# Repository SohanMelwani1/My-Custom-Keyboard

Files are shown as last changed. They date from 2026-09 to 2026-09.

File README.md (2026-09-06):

# My-Custom-Keyboard
My own Custom 60% Mechanical Keyboard

[Click here to open and view firmware repository](https://github.com/SohanMelwani1/RMK-My-custom-Keyboard)

BOM link: https://docs.google.com/spreadsheets/d/1pmS31pF6GHp4k1bNOez-trRHEgPxX3IoW4xAfGn9qzQ/edit?gid=0#gid=0

# Features
- 3 Macros
- Anti-Ghosting
- customizable keycaps and switches
- swappable switches without needing to re-solder it
- 60% mechanical keyboard
- no screws required
- 3d printed case
- Matrix layout
- 61 keys

___

While making this I learnt How Matrix keyboards work, types of mounting of keyboards, Schematic and how to use it, PCB wiring, importing pcb to fusion and creating case, Firmware and about keyboards in general, this was my first PCB I have ever designed

___

PCB without ground



PCB



PCB 3d view



Schematic stabilizers and mounting hole



Schematic RaspberryPi_Pico



Schematic Matrix with switches and diodes



Full schematic



Full 3d model



3d model case, plate and top frame



3d model case 



3d model plate


3d model top frame


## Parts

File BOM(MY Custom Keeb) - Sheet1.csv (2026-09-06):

Material/part | Amount | INR Price(including Tax and shipping) | USD price(including tax and shipping) | Link | Note
Gateron Hotswap sockets | 62 Pieces | ₹750 | $7.94 | https://stackskb.com/store/gateron-hotswap-sockets/
PLA matte(numakers) | 1Kg | ₹868.5 | $9.20 | https://india.numakers.com/products/pla-matte?variant=45679205482665
Key cap set | Set of 1 | ₹1399 | $14.82 | https://meckeys.com/shop/accessories/keyboard-accessories/keycaps/comic-style-keycap-set/
Gateron Mechanical Switches | 7 sets(10 per set) | ₹1260 | $13.34 | https://www.thecosmicbyte.com/product/gateron-mechanical-switches-compatible-with-cosmic-byte-hot-swappable-keyboards-qty-1pc/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
RaspberryPi_PICO | 1 piece | ₹552 | $5.85 | https://sharvielectronics.com/product/raspberry-pi-pico-rp2040-with-basic-kit/ | Ordering with diode(so i combined both shiping to make it cheaper
1N4148W-T4 (Diode) | 80 pieces(minimum) | ₹189 | $2.00 | https://sharvielectronics.com/product/1n4148w-t4-high-speed-fast-switching-diode-sod-123-package/ | Ordering with RaspbberyPi_PICO(so i combined both shiping to make it cheaper
Soldering Iron | 1 Piece | ₹299 | $3.17 | https://www.amazon.in/THEMISTO-passion-Themisto-Beginners-Soldering/dp/B07PM6134P/ref=sr_1_6?sr=8-6
Heat resistant gloves(for soldering) | 1 pair of gloves | ₹270 | $2.86 | https://www.amazon.in/KOOCU-Resistant-Temperature-Breathable-Electronics/dp/B0H7YN7SBV
Stabalizer | 1 set | ₹730 | $7.73 | https://neomacro.in/products/cherry-stabilizer-set-geon-and-c3?_pos=3&_sid=9a6134911&_ss=r
PCB | 5(minimum) | ₹4635 | $49.09 | https://robu.in/product/online-pcb-manufacturing-service/
Total cost |  | ₹10,952.5 | $116.00

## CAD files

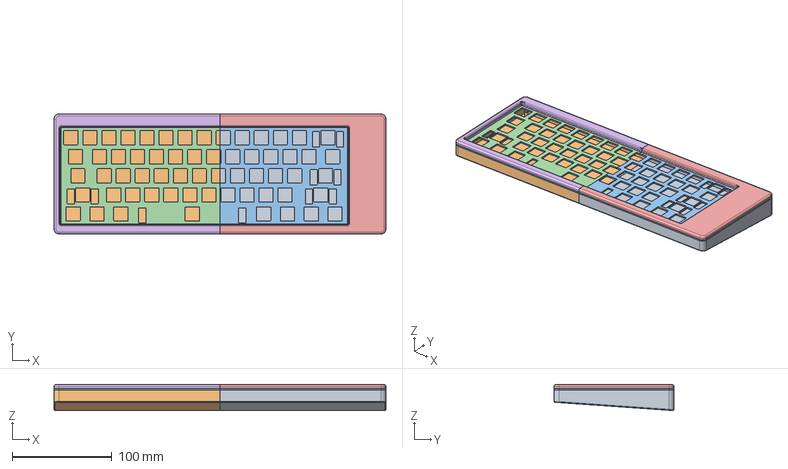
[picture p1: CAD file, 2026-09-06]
CAD(print)/Keeb-full Case(step).step
332.0 x 120.0 x 26.2 mm
My-keebs_PCB

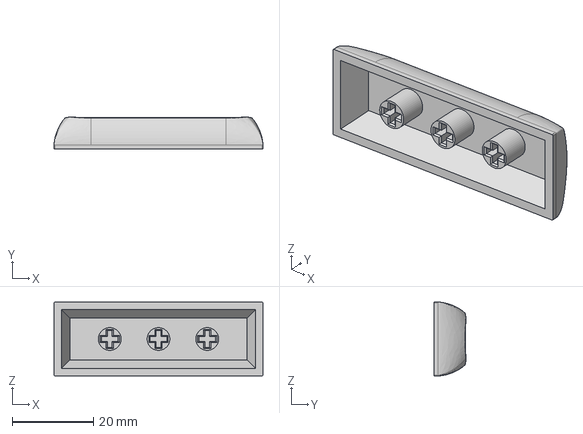
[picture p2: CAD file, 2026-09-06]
Assets/keycaps/DSA 2.75u.step
51.5 x 7.91 x 18.2 mm

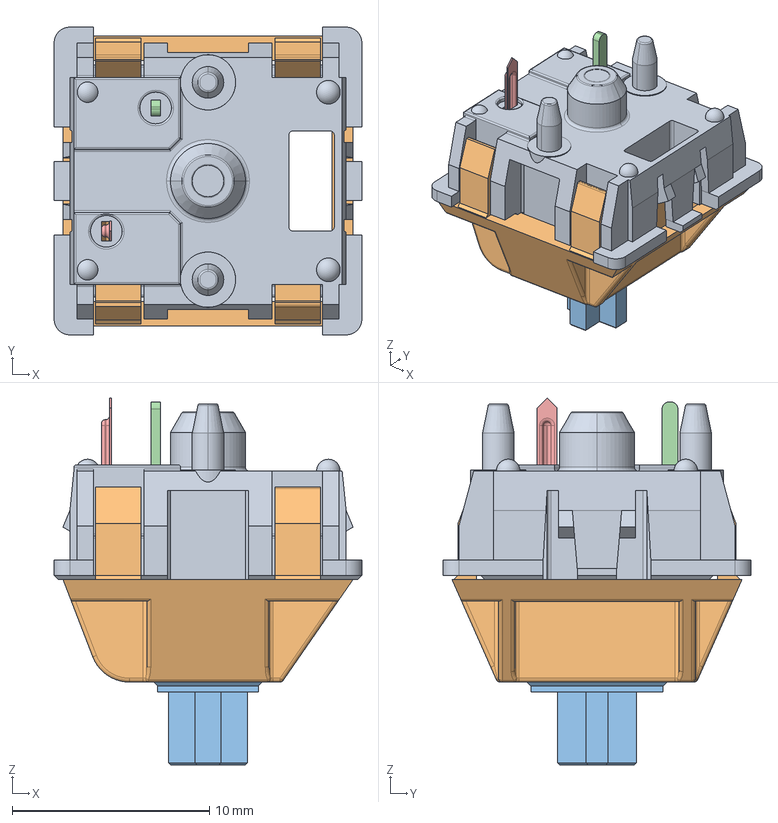
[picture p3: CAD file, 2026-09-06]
Assets/Switch/MX_switch.stp
15.6 x 15.6 x 18.6 mm
MX_DOWN
MX_UP
UP_MX
MX_PIN
MX_SPRING
MX_CLICK

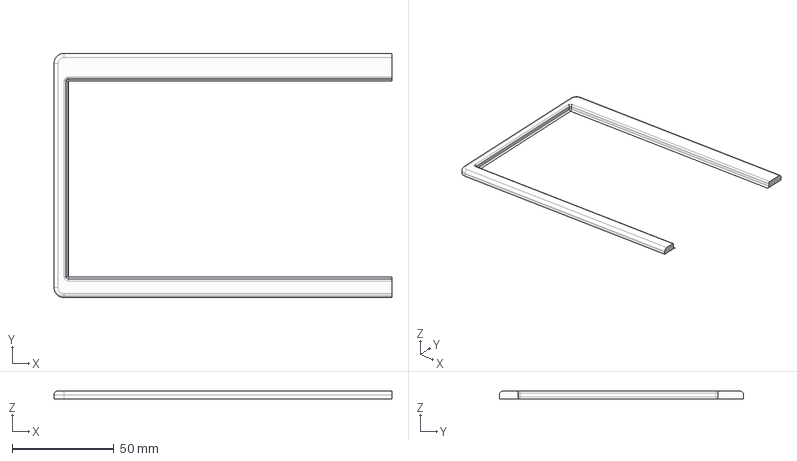
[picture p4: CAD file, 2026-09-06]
CAD(print)/Keeb top frame-left(step).step
166.0 x 120.0 x 4.00 mm
My-keebs_PCB

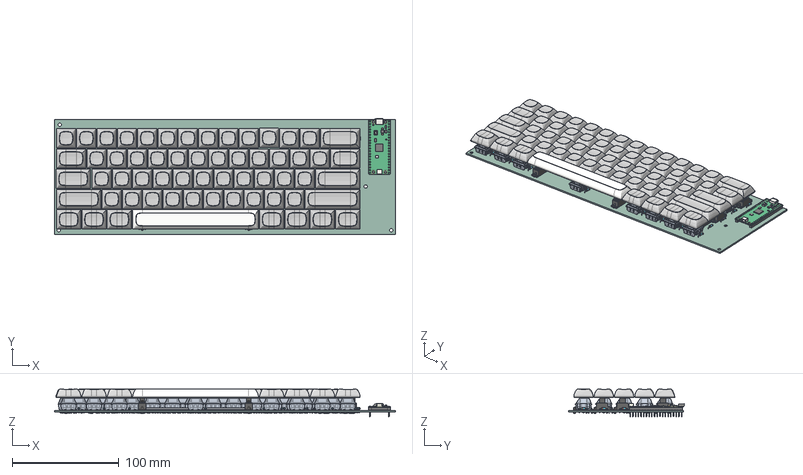
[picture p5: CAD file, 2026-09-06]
PCB/Keeb.step
320.0 x 108.8 x 26.3 mm
D_DO-35_SOD27_P7.62mm_Horizontal x 61
MX_DOWN x 61
MX_UP x 61
UP_MX x 61
MX_PIN x 61
MX_SPRING x 61
MX_CLICK x 61
MX Mount v1 x 46
RaspberryPi_Pico_H_Module_KiCad
RaspberryPi_Pico_Header_DIP-40_H2.54mm_KiCad
DSA 1.5u x 2
DSA 1.25u x 7
body_l x 5
stem_l x 5
body_r x 5
stem_r x 5
wire_2u x 4
DSA 2.25u x 2
DSA Spacebar 6.25u (50mm spacing)
DSA 2.75u
DSA 1.75u
wire_6_25u
DSA 2u
My-keebs_PCB

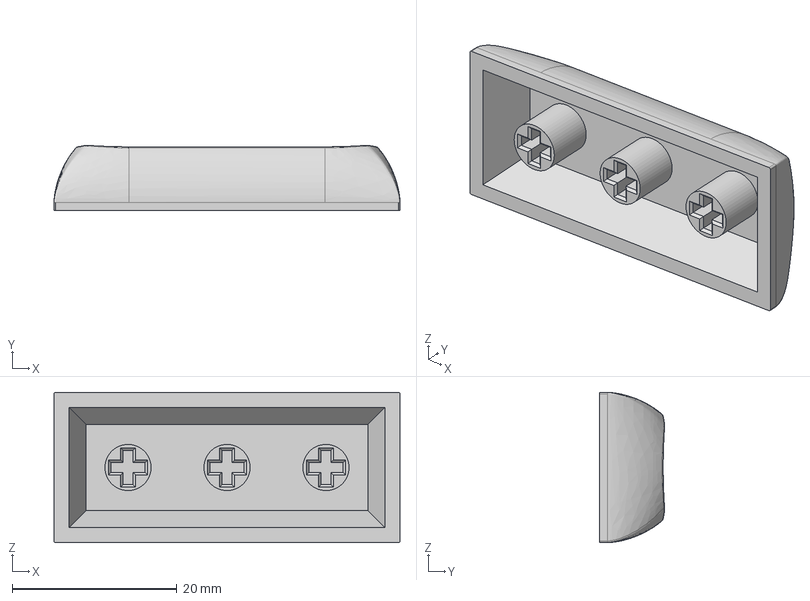
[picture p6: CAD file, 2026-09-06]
Assets/keycaps/DSA 2.25u.step
42.0 x 7.91 x 18.2 mm

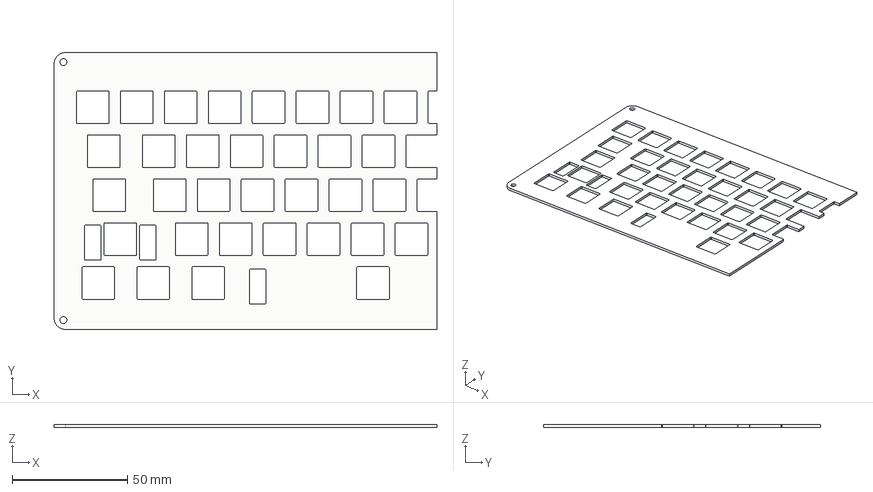
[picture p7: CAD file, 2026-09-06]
CAD(print)/Keeb plate-left(step).step
166.0 x 120.0 x 1.50 mm
My-keebs_PCB

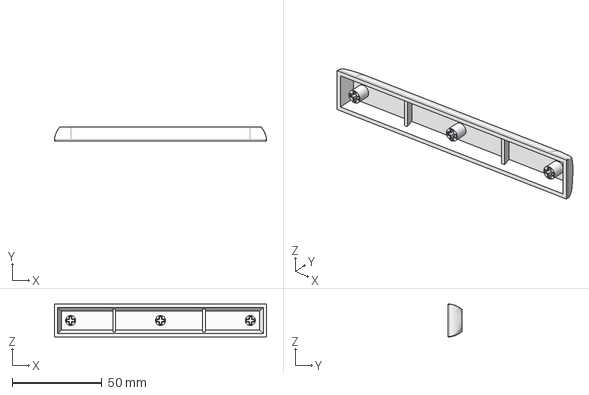
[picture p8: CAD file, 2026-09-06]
Assets/keycaps/DSA Spacebar 6.25u (50mm spacing).step
118.0 x 8.00 x 18.2 mm

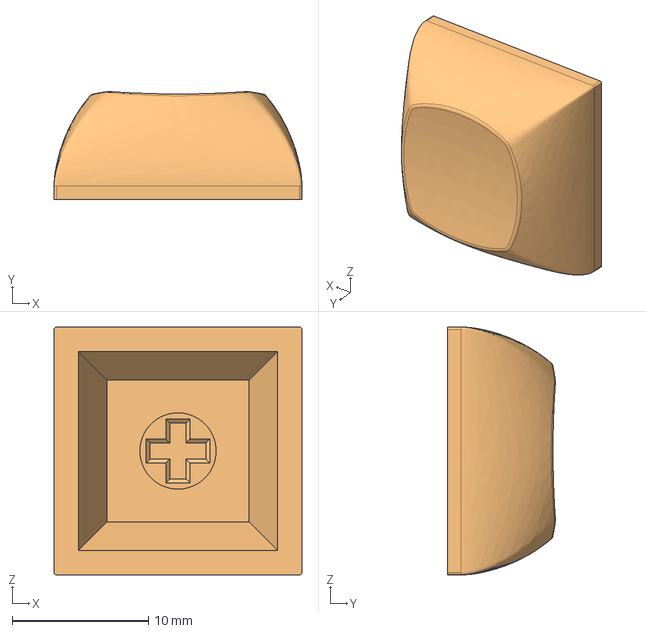
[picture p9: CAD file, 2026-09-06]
Assets/keycaps/DSA 1u.step
18.2 x 7.91 x 18.2 mm

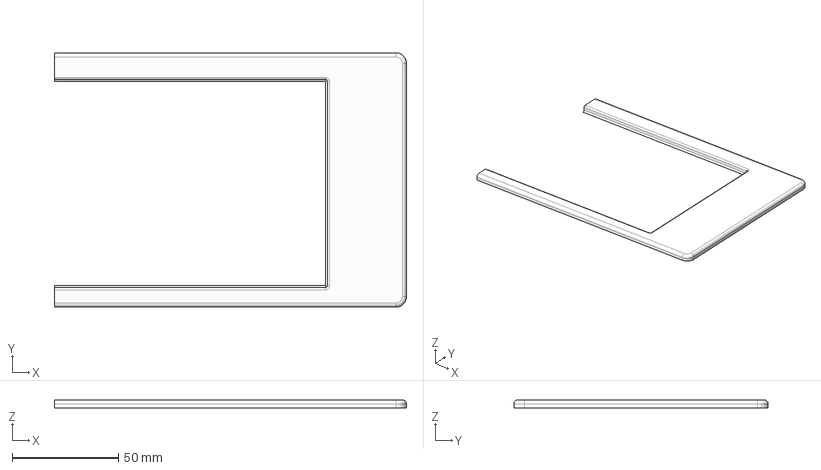
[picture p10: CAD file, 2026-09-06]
CAD(print)/Keeb top fram-right(step).step
166.0 x 120.0 x 4.00 mm
My-keebs_PCB

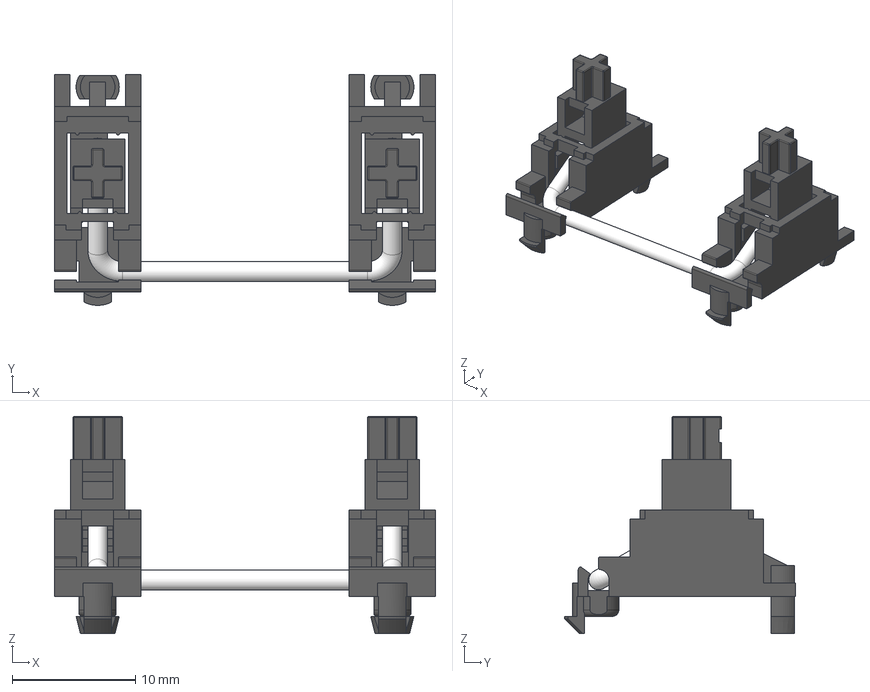
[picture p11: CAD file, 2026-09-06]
Assets/keycaps/stabilizer_2u.step
30.9 x 18.7 x 17.6 mm
body_l
stem_l
body_r
stem_r
wire_2u

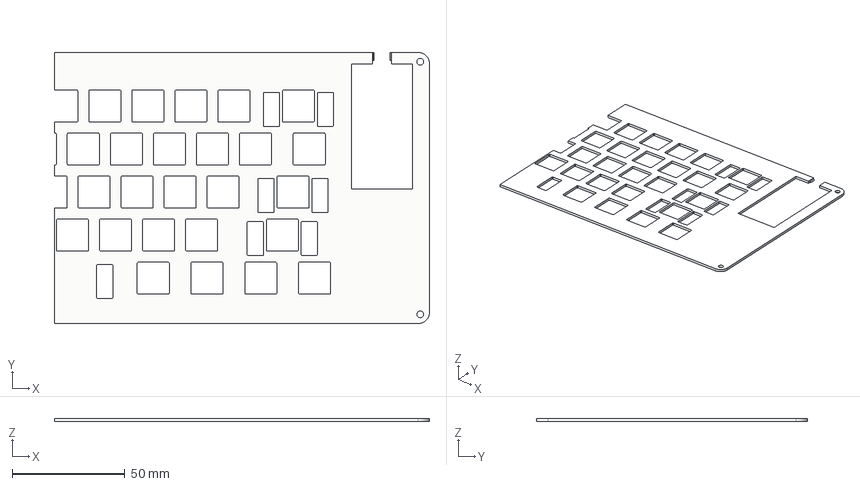
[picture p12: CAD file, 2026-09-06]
CAD(print)/Keeb plate-right(step).step
166.0 x 120.0 x 1.50 mm
My-keebs_PCB

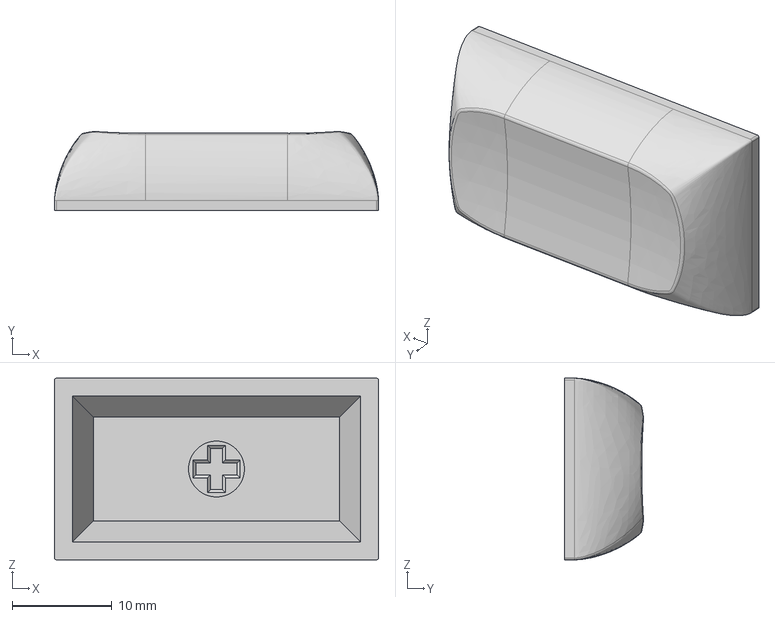
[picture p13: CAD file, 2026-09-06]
Assets/keycaps/DSA 1.75u.step
32.5 x 7.91 x 18.2 mm

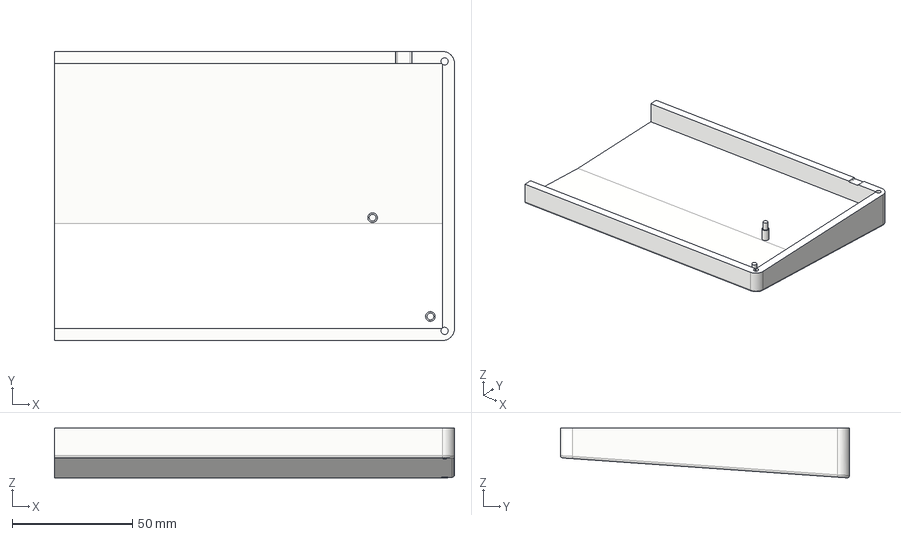
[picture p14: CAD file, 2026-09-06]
CAD(print)/Keeb case-right(step).step
166.0 x 120.0 x 20.7 mm
My-keebs_PCB

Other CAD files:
Assets/keycaps/stabilizer_6_25u.step
CAD(print)/Keeb case-left(step).step
Assets/keycaps/DSA 1.25u.step
Assets/keycaps/DSA 1.5u.step
Assets/keycaps/DSA 2u.step
CAD(print)/Keeb case-right(step).3mf

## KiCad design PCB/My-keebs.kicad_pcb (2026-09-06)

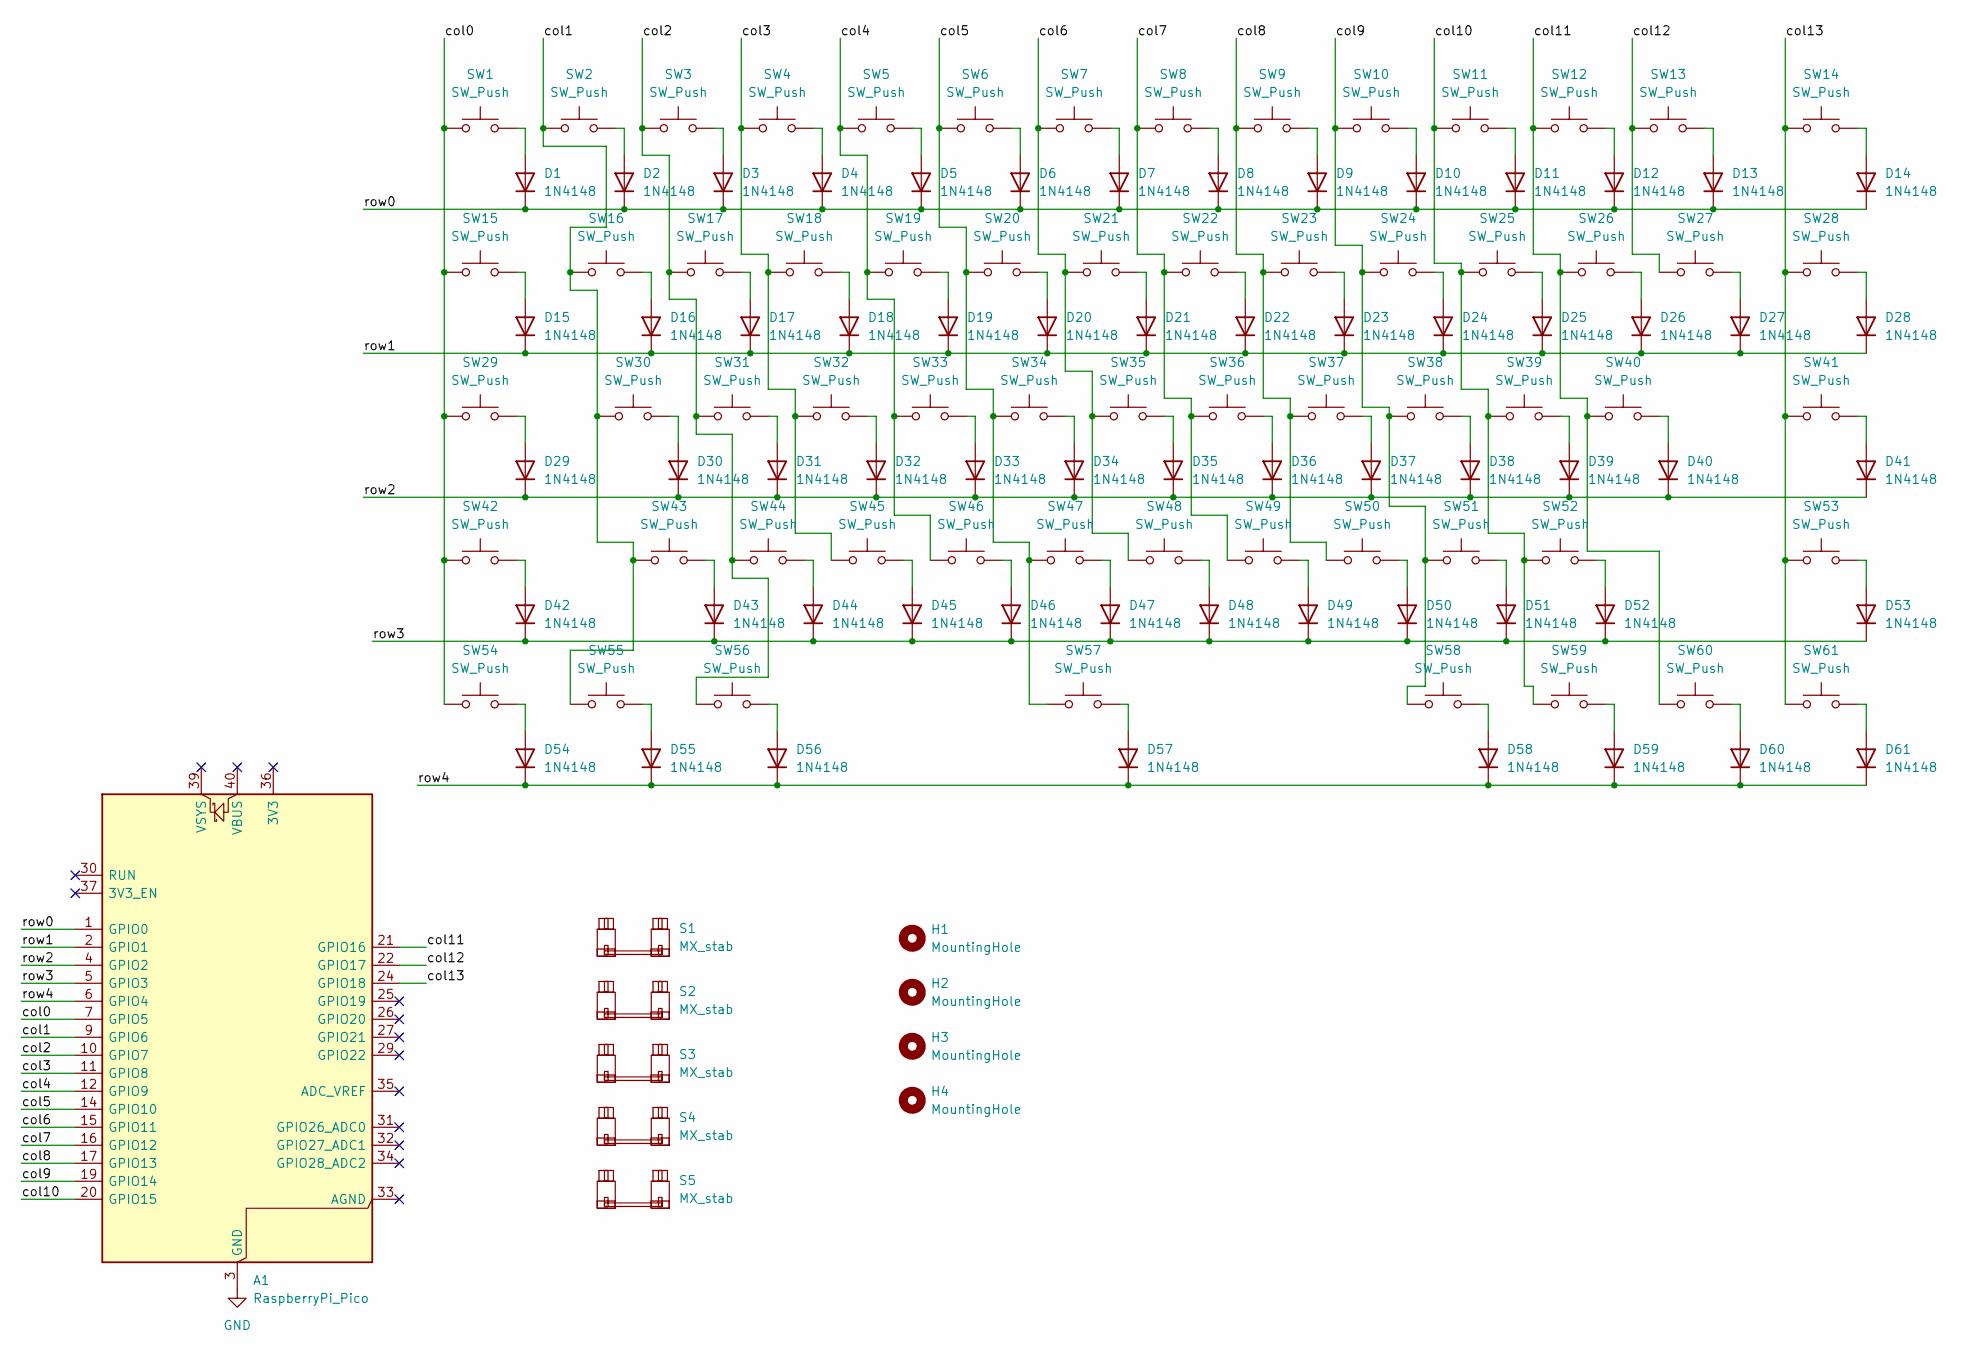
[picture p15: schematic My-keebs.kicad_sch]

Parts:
A1: RaspberryPi_Pico; RaspberryPi_Pico_Common_THT
D1, D2, D3, D4, D5, D6, D7, D8, D9, D10, D11, D12, D13, D14, D15, D16, D17, D18, D19, D20, D21, D22, D23, D24, D25, D26, D27, D28, D29, D30, D31, D32, D33, D34, D35, D36, D37, D38, D39, D40, D41, D42, D43, D44, D45, D46, D47, D48, D49, D50, D51, D52, D53, D54, D55, D56, D57, D58, D59, D60, D61: 1N4148; D_DO-35_SOD27_P7.62mm_Horizontal
H1, H2, H3, H4: MountingHole; MountingHole_3.2mm_M3
S1, S2, S3, S5: MX_stab; STAB_MX_2u
S4: MX_stab; STAB_MX_6.25u
SW1, SW2, SW3, SW4, SW5, SW6, SW7, SW8, SW9, SW10, SW11, SW12, SW13, SW14, SW15, SW16, SW17, SW18, SW19, SW20, SW21, SW22, SW23, SW24, SW25, SW26, SW27, SW28, SW29, SW30, SW31, SW32, SW33, SW34, SW35, SW36, SW37, SW38, SW39, SW40, SW41, SW42, SW43, SW44, SW45, SW46, SW47, SW48, SW49, SW50, SW51, SW52, SW53, SW54, SW55, SW56, SW57, SW58, SW59, SW60, SW61: SW_Push; SW_MX_1u

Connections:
/col0: A1.7 (GPIO5), SW1.1, SW15.1, SW29.1, SW42.1, SW54.1
/col1: A1.9 (GPIO6), SW2.1, SW16.1, SW30.1, SW43.1, SW55.1
/col2: A1.10 (GPIO7), SW3.1, SW17.1, SW31.1, SW44.1, SW56.1
/col3: A1.11 (GPIO8), SW4.1, SW18.1, SW32.1, SW45.1
/col4: A1.12 (GPIO9), SW5.1, SW19.1, SW33.1, SW46.1
/col5: A1.14 (GPIO10), SW6.1, SW20.1, SW34.1, SW47.1, SW57.1
/col6: A1.15 (GPIO11), SW7.1, SW21.1, SW35.1, SW48.1
/col7: A1.16 (GPIO12), SW8.1, SW22.1, SW36.1, SW49.1
/col8: A1.17 (GPIO13), SW9.1, SW23.1, SW37.1, SW50.1
/col9: A1.19 (GPIO14), SW10.1, SW24.1, SW38.1, SW51.1, SW58.1
/col10: A1.20 (GPIO15), SW11.1, SW25.1, SW39.1, SW52.1, SW59.1
/col11: A1.21 (GPIO16), SW12.1, SW26.1, SW40.1, SW60.1
/col12: A1.22 (GPIO17), SW13.1, SW27.1
/col13: A1.24 (GPIO18), SW14.1, SW28.1, SW41.1, SW53.1, SW61.1
/row0: A1.1 (GPIO0), D1.1 (K), D2.1 (K), D3.1 (K), D4.1 (K), D5.1 (K), D6.1 (K), D7.1 (K), D8.1 (K), D9.1 (K), D10.1 (K), D11.1 (K), D12.1 (K), D13.1 (K), D14.1 (K)
/row1: A1.2 (GPIO1), D15.1 (K), D16.1 (K), D17.1 (K), D18.1 (K), D19.1 (K), D20.1 (K), D21.1 (K), D22.1 (K), D23.1 (K), D24.1 (K), D25.1 (K), D26.1 (K), D27.1 (K), D28.1 (K)
/row2: A1.4 (GPIO2), D29.1 (K), D30.1 (K), D31.1 (K), D32.1 (K), D33.1 (K), D34.1 (K), D35.1 (K), D36.1 (K), D37.1 (K), D38.1 (K), D39.1 (K), D40.1 (K), D41.1 (K)
/row3: A1.5 (GPIO3), D42.1 (K), D43.1 (K), D44.1 (K), D45.1 (K), D46.1 (K), D47.1 (K), D48.1 (K), D49.1 (K), D50.1 (K), D51.1 (K), D52.1 (K), D53.1 (K)
/row4: A1.6 (GPIO4), D54.1 (K), D55.1 (K), D56.1 (K), D57.1 (K), D58.1 (K), D59.1 (K), D60.1 (K), D61.1 (K)
GND: A1.3 (GND), A1.8 (GND), A1.13 (GND), A1.18 (GND), A1.23 (GND), A1.28 (GND), A1.38 (GND)
unnamed: D1.2 (A), SW1.2
unnamed: D2.2 (A), SW2.2
unnamed: D3.2 (A), SW3.2
unnamed: D4.2 (A), SW4.2
unnamed: D5.2 (A), SW5.2
unnamed: D6.2 (A), SW6.2
unnamed: D7.2 (A), SW7.2
unnamed: D8.2 (A), SW8.2
unnamed: D9.2 (A), SW9.2
unnamed: D10.2 (A), SW10.2
unnamed: D11.2 (A), SW11.2
unnamed: D12.2 (A), SW12.2
unnamed: D13.2 (A), SW13.2
unnamed: D14.2 (A), SW14.2
unnamed: D15.2 (A), SW15.2
unnamed: D16.2 (A), SW16.2
unnamed: D17.2 (A), SW17.2
unnamed: D18.2 (A), SW18.2
unnamed: D19.2 (A), SW19.2
unnamed: D20.2 (A), SW20.2
unnamed: D21.2 (A), SW21.2
unnamed: D22.2 (A), SW22.2
unnamed: D23.2 (A), SW23.2
unnamed: D24.2 (A), SW24.2
unnamed: D25.2 (A), SW25.2
unnamed: D26.2 (A), SW26.2
unnamed: D27.2 (A), SW27.2
unnamed: D28.2 (A), SW28.2
unnamed: D29.2 (A), SW29.2
unnamed: D30.2 (A), SW30.2
unnamed: D31.2 (A), SW31.2
unnamed: D32.2 (A), SW32.2
unnamed: D33.2 (A), SW33.2
unnamed: D34.2 (A), SW34.2
unnamed: D35.2 (A), SW35.2
unnamed: D36.2 (A), SW36.2
unnamed: D37.2 (A), SW37.2
unnamed: D38.2 (A), SW38.2
unnamed: D39.2 (A), SW39.2
unnamed: D40.2 (A), SW40.2
unnamed: D41.2 (A), SW41.2
unnamed: D42.2 (A), SW42.2
unnamed: D43.2 (A), SW43.2
unnamed: D44.2 (A), SW44.2
unnamed: D45.2 (A), SW45.2
unnamed: D46.2 (A), SW46.2
unnamed: D47.2 (A), SW47.2
unnamed: D48.2 (A), SW48.2
unnamed: D49.2 (A), SW49.2
unnamed: D50.2 (A), SW50.2
unnamed: D51.2 (A), SW51.2
unnamed: D52.2 (A), SW52.2
unnamed: D53.2 (A), SW53.2
unnamed: D54.2 (A), SW54.2
unnamed: D55.2 (A), SW55.2
unnamed: D56.2 (A), SW56.2
unnamed: D57.2 (A), SW57.2
unnamed: D58.2 (A), SW58.2
unnamed: D59.2 (A), SW59.2
unnamed: D60.2 (A), SW60.2
unnamed: D61.2 (A), SW61.2

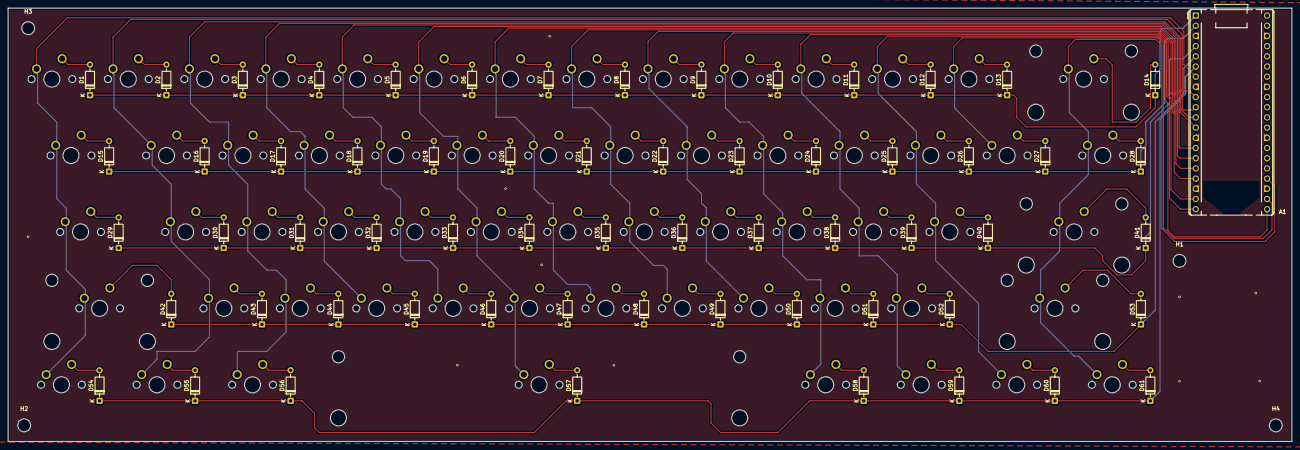
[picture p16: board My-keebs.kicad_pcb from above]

Board: 2 copper layers, 320.0 x 108.0 mm, 132 parts (0 on the bottom side), 81 nets.

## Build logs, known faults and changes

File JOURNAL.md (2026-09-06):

# Day1 (25/8/2026)

I first started with planning how exactly I am going to make my keyboard,
I decided I was going to have a 60% keyboard with 61 keys
for This keyboard I am using the 'RaspberryPi_Pico' and I am planning on using matrix for my keyboard.
Today I created my full schematic




Hours spent today: 2 hours 15 minutes

___

# Day2 (26/8/2026)
I started my pcb layout as what I had planned earlier before. When I finished my layout I asked a friend I met on hack club for feedback, He told me that the switches weren't evenly spaced and told me that I had to replace all of the keys and that i had used a few extra stabalizers.

(this is how it looked like, it took me so long to manually place each of the keys)

Then I was told to use a plugin which could help me layout my keys, it was quite difficult navigating in the PCB since this was my first time using it, anyways once i used the plugin it made it much easier for me, the keys all positioned.

Then I asked him for feedback and improvement he said to rotate the diode 90 degrees and repositioned it, i kept repositioning it until I got what I was looking for


(this is what i got after mutiple tries of repositioning)


Then once again feedback, he told me to change the side of the diode(put it on the right of the switch since it would be much easier to route them.

today I finished the layout, diode and switch placement throught today I learnt lots of new tools.

Hours spent today: 4 Hours 30 minutes 

___

# day 3 (27/8/2026)

Today I had started with the matrix and the routings
Fist I had learnt how to use the route single track feature then started with the columns then i connected the row

It looked good, But once I connected the first wire to the raspberryPi_pico, I readlized that my rows weren't apperaing and there were lots of col 0 instead in many pins 

So I tried trouble shooting it and finding a solution, I first went back to my schematic to save it and update it in pcb, but that didn't work, then i realized that pins which weren't being used was marked x in the guide so I implemented that.

this is the picture in the guide 

However that still didnt work, but I asked my friend for help on it, he said that there was no ground pin and that might be the reason to it. once i replaced the x with the ground pin I thought it was all solved, but still didn't change the col0



I was looking at each switch in my schematic and noticed that I was actually short cicuiting it, I was adding the rows in the slot of the switches instead of the diode and was connecting each row to col0


then i made the changes and it finally worked!!




then I connected/routed all of the wires to the RaspberryPi_pico,
Once i finished I checked design rule checker but got some errors (gnd pins weren't connected)
then I asked my friend for feedback again on the pcb, He told me to grnd both the copper plates
I went back to the guide and learnt how to do it, but still got errors, and I realized that while making the connections I had extended the cut and the pico's cable wouldn't fit, so I had moved it up and attached the routes to it, luckily the routes were just a few cm away.



Once i finished I started planning my mounting holes and there was verry less space, 


While adding it I learnt how use the move precisley feature (shift+m)
and used it to exactly position my mounting holes



hours spent today in total: 6 hours

___

# Day 4 (4/9/2026)

I had took like a week brake since I had my exams

Today, I added footprints like the Cherry Mx switches and the keycaps and stabalizer to each slot
sadly I had to manually position each switch, key cap and stabilizer in each slot since I hadn't set footprints earlier so it took quite some time to place each one manually

Switches





Keycaps and stabalizer



(while making the stabilizers first i had positioned them facing backwards(the wire) so then I had to rotate each, but luckly this time I only had to rotate 5)



Then I learnt how to import to fusion, At first it wasn't working I tried different methords then I finally found why it wasn't uploading to fusion, I learnt that if it is in the KiCad file, it won't let you upload, so I draged my step file to dowanloads then it worked

Hours spent today: 2 Hours 30 minutes

___

# Day 5 (5/9/2026)

Today I started with the 3d model

First I started by making the case border, while making it I added some extra space in the bottom for the hot swaps to go there and fit, then I made the plate, While making it I added a .1mm kerf for the slots because I am going to be 3d printing it and since filament like PLA can expand a little and because 3d printing isn't perfect, I used section analysis a lot and it helped me so much it also made stuff easier anyways, I made the plate so that its the same size as the case and would work for my sandwich mount next I added the hole in the front of my keyboard for the micro USB ( RaspberryPi_Pico ). Then I added the PCB mounting hole holder so that it doesn't put to much pressure on the plate. Later I added a cover for the raspberry pi on the top frame since the plate wasn't covering it. then I added a 4 degrees tilt to prevent wrist pain. I finished the case.








Hours spent today: 6 Hours 10 minutes

___

# Day 6 (6/9/2026)

Today I was just finishing up what was left. I Made the firmware, I didn't even know what it was until today and surprisingly it wasn't that difficult. Then I downloaded the files, tried to find a way to make my BOM cheaper so that Keeb doesn't over spend money on mine and created it. I also added downloads, CAD files, PCB files then fixed some errors in the firmware.







Hours spent today: 3 hours 35 minutes

___

# Total Hours Spent: 24 hours and 50 minutes

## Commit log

2026-08-28 Update JOURNAL.md with Day 2 progress
    Documented progress on PCB layout and feedback received.
2026-08-28 Revise JOURNAL.md with day 3 updates
    Updated journal entry with detailed progress on matrix routing, troubleshooting issues with connections, and adjustments made for mounting holes.
2026-09-06 Document Day 5 progress on 3D keyboard model
    Detailed the process of creating a 3D model for a keyboard case, including design considerations and adjustments made for component fitting.
2026-09-06 Create Cherry MX switch
2026-09-06 Create Cad files
2026-09-06 Create PCB file
2026-09-06 Update README with BOM link and learning insights
    Added BOM link and personal learning experiences related to keyboard design.
2026-10-26 Update README with case design improvements
    Added details about securing the case pieces with corner holes.
